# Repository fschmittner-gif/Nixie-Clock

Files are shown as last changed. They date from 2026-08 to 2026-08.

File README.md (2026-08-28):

# Nixie Clock

The goal of this project is to build your own Nixie Clock and get a result like this: 

NixieClockPNG

## Resources
### Controlling the Tubes

The project is based on the idea of controlling the Nixie tubes with old russian driver parts utilizing an arduino nano based on this [article](https://www.instructables.com/Controlling-Nixie-Tube-With-Arduino-Using-K155ID1-/) 

Tubes

### Real Time Clock (RTC)

In order to keep the time during a power outage or when moving the clock a RTC added to the project. For this purpose the DS3231 was used due to its low cost, easy I2C comunnication and available Arduino libraries.

RTC

## Designing the PCB

For the PCB Design a Schematic and Layout were designed in Fusion 360 and available for download and use. Before ordering your own PCBs, the DC Jack placement should be adapted as in the current design it sits inverted on the TOP Side. For my build, I fixed it by manipulating the installed DC Jack before soldering it onto the PCB.  

Rendering of PCB V1:

Schematic V1 3D BOTTOM
Schematic V1 3D TOP

## BOM

| Reference Designators | Quantity | Description | Package | Value |
|---|---|---|---|---|
| ARDUINO_NANO | 1 | Arduino Nano V3.0 | ARDUINO_NANO |  |
| C1, C2, C3, C4, C5 | 5 | CAPACITOR, European symbol | C0603 | 100n |
| C6, C7 | 2 | CAPACITOR, European symbol | C0603 | 10u |
| D1 | 1 | DCDC Converter | NIXIE_DCDC | DCDC_NIXIE |
| DC_JACK | 1 | 2.1mm x 5.5mm THM DC jack with internal switch. Digikey part #PJ-102A, 4UCON part #05537 | PJ-102A | 2.1MMJACKTHM |
| DCDC_IN, DCDC_OUT | 2 | PIN HEADER | 1X02 |  |
| L1 | 1 | Linear Regulator 5V | TO220 | L7805_5V |
| NX1, NX2, NX3, NX4 | 4 | IN-14: medium numeric frontview nixie tube | IN-14 | IN-14 |
| R1, R2, R3, R4 | 4 | RESISTOR, European symbol | R1206 | 10k |
| RTC | 1 | RTC Module with Battery and EEPROM based on DS3231 and AT24C32 chips | RTC-DS3231-AT24C32 | RTC-DS3231-AT24C32 |
| U1, U2, U3, U4 | 4 | Nixie Drivers | DIL16 | K155ID1 |

## Software

The Software is split into 2 parts: "SetTime" and "Control".

First the "SetTime" code has to be flashed to the Arduino in order to set the RTC to the current time. Afterwards the "Coltrol" code shall be flashed to actually display the time on the Nixie Tubes. I recommend using the Arduino IDE for programming.

## Case

A ready to print 3D case for the designed PCB is available to download. 

Gehäuse V2

## Lizenzierung

Dieses Projekt ist dual lizenziert:
- Die **Software und Firmware** steht unter der [Apache 2.0 Lizenz](LICENSE-SOFTWARE).
- Die **Hardware-Designs** (Schaltpläne, CAD-Daten, PCB-Layouts) stehen unter der [CERN-OHL-P v2 Lizenz](LICENSE-HARDWARE).

Beide Lizenzen schließen jegliche Haftung oder Gewährleistung aus. Die Nutzung erfolgt auf eigene Gefahr.

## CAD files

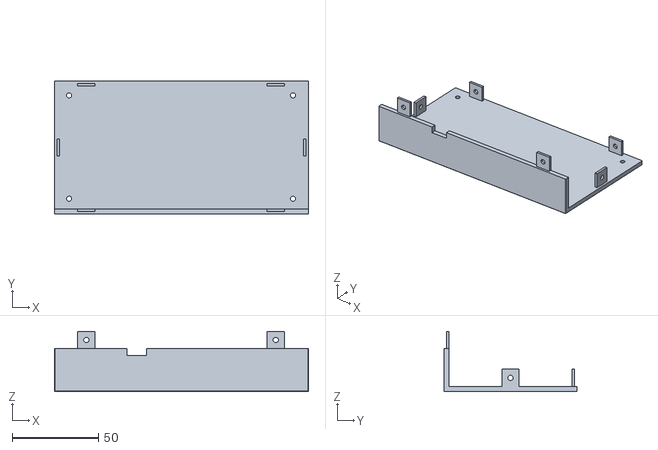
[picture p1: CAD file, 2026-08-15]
Housing/Bottom_V2.stl
147.5 x 77.5 x 35.0

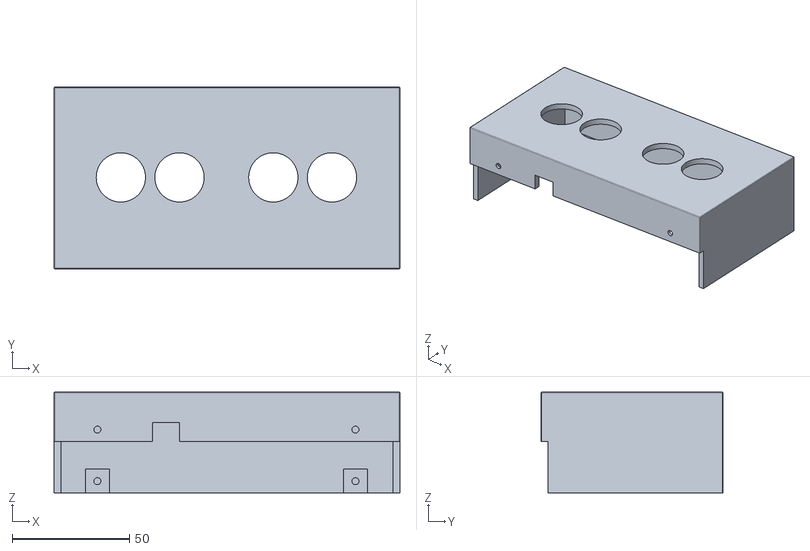
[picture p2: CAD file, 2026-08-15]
Housing/Top_V2.stl
147.5 x 77.5 x 43.0

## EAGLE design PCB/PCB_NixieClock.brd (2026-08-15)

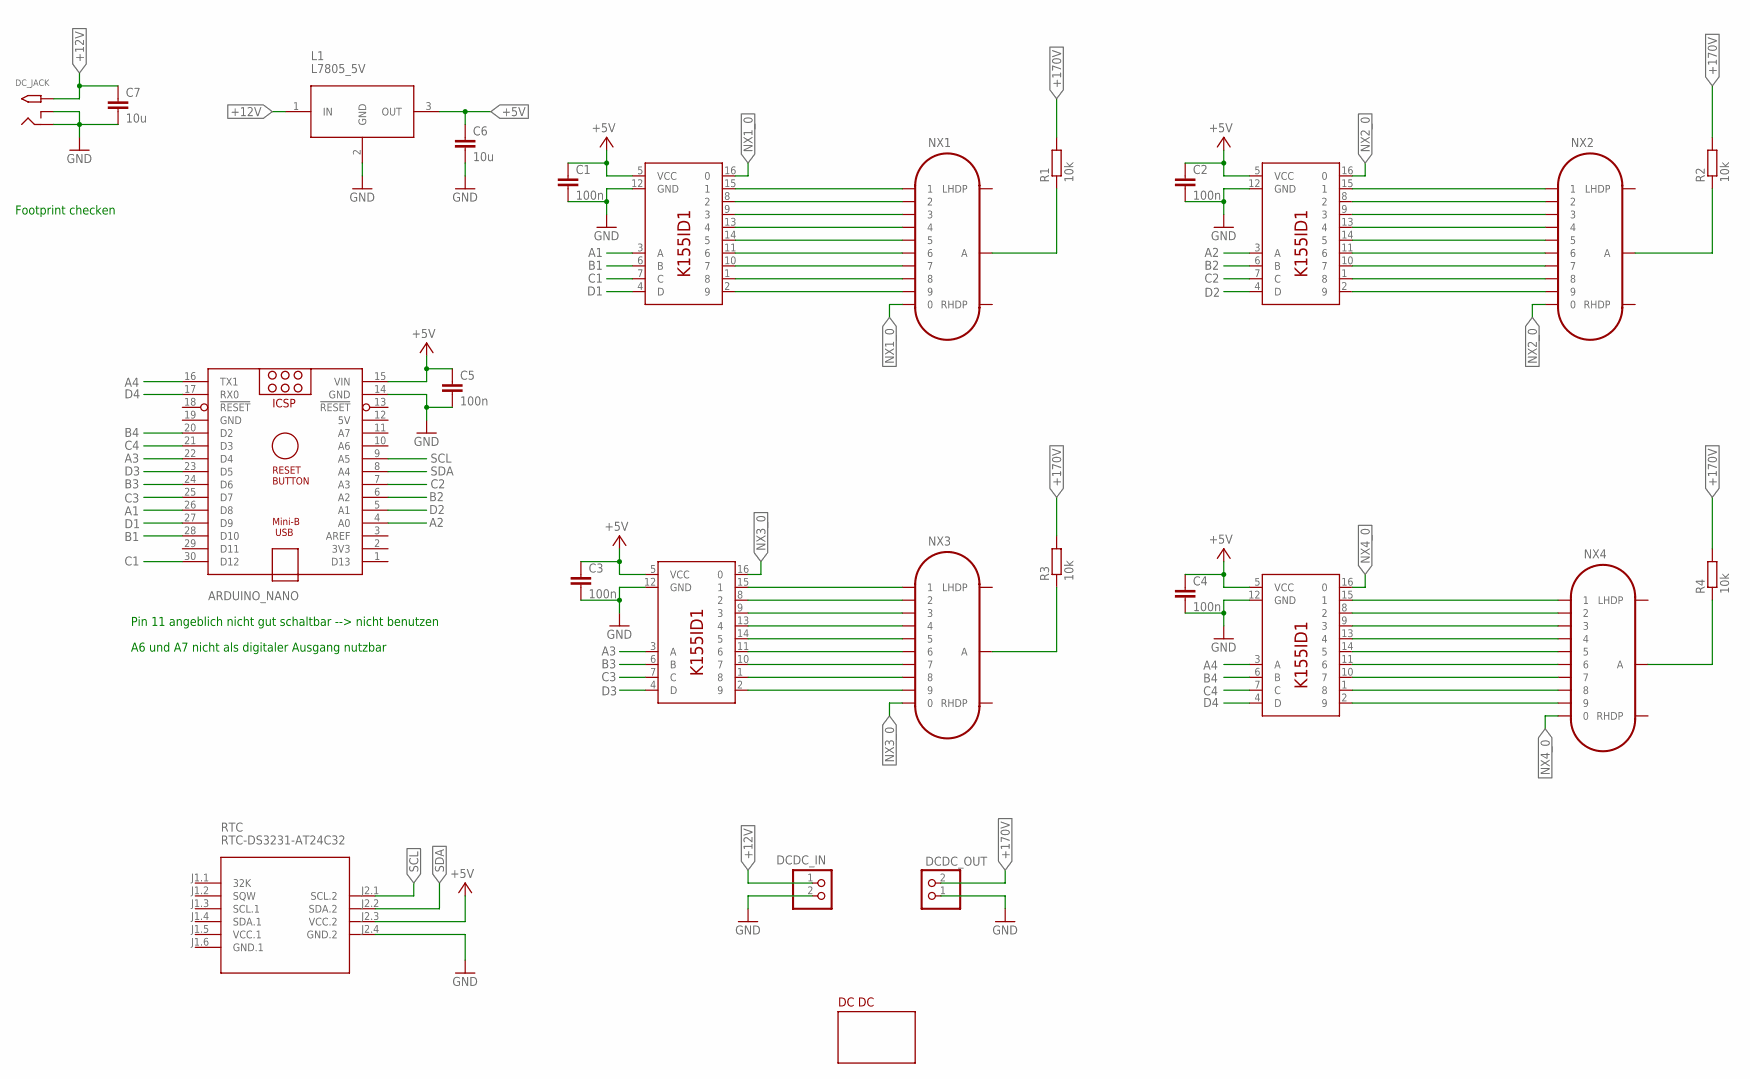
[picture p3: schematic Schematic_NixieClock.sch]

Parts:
ARDUINO_NANO: ARDUINO_NANO
C1, C2, C3, C4, C5: 100n; C0603
C6, C7: 10u; C0603
D1: DCDC_NIXIE; NIXIE_DCDC
DCDC_IN: PINHD-1X2; 1X02
DCDC_OUT: PINHD-1X2; 1X02
DC_JACK: 2.1MMJACKTHM; PJ-102A
L1: L7805_5V; TO220
NX1, NX2, NX3, NX4: IN-14
R1, R2, R3, R4: 10k; R1206
RTC: RTC-DS3231-AT24C32
U1, U2, U3, U4: K155ID1; DIL16

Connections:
5V: ARDUINO_NANO.12 (5V)
+5V: ARDUINO_NANO.15 (VIN), C1.1, C2.1, C3.1, C4.1, C5.1, C6.1, L1.3 (OUT), RTC.J2.3 (VCC.2), U1.5 (VCC), U2.5 (VCC), U3.5 (VCC), U4.5 (VCC)
+12V: C7.1, DCDC_IN.1, DC_JACK.TIP, L1.1 (IN)
+170V: DCDC_OUT.2, R1.2, R2.2, R3.2, R4.2
A1: ARDUINO_NANO.26 (D8), U1.3 (A)
A2: ARDUINO_NANO.4 (A0), U3.3 (A)
A3: ARDUINO_NANO.22 (D4), U2.3 (A)
A4: ARDUINO_NANO.16 (TX1), U4.3 (A)
B1: ARDUINO_NANO.28 (D10), U1.6 (B)
B2: ARDUINO_NANO.6 (A2), U3.6 (B)
B3: ARDUINO_NANO.24 (D6), U2.6 (B)
B4: ARDUINO_NANO.20 (D2), U4.6 (B)
C1: ARDUINO_NANO.30 (D12), U1.7 (C)
C2: ARDUINO_NANO.7 (A3), U3.7 (C)
C3: ARDUINO_NANO.25 (D7), U2.7 (C)
C4: ARDUINO_NANO.21 (D3), U4.7 (C)
D1: ARDUINO_NANO.27 (D9), U1.4 (D)
D2: ARDUINO_NANO.5 (A1), U3.4 (D)
D3: ARDUINO_NANO.23 (D5), U2.4 (D)
D4: ARDUINO_NANO.17 (RX0), U4.4 (D)
GND: ARDUINO_NANO.14 (GND), ARDUINO_NANO.19 (GND), C1.2, C2.2, C3.2, C4.2, C5.2, C6.2, C7.2, DCDC_IN.2, DCDC_OUT.1, DC_JACK.RING, DC_JACK.RING_SW, L1.2 (GND), RTC.J2.4 (GND.2), U1.12 (GND), U2.12 (GND), U3.12 (GND), U4.12 (GND)
GND.1: RTC.J1.6 (GND.1)
unnamed: NX1.1, U1.15 (1)
unnamed: NX1.2, U1.8 (2)
unnamed: NX1.3, U1.9 (3)
unnamed: NX1.4, U1.13 (4)
unnamed: NX1.5, U1.14 (5)
unnamed: NX1.6, U1.11 (6)
unnamed: NX1.7, U1.10 (7)
unnamed: NX1.8, U1.1 (8)
unnamed: NX1.9, U1.2 (9)
unnamed: NX3.1, U2.15 (1)
unnamed: NX3.2, U2.8 (2)
unnamed: NX3.3, U2.9 (3)
unnamed: NX3.4, U2.13 (4)
unnamed: NX3.5, U2.14 (5)
unnamed: NX3.6, U2.11 (6)
unnamed: NX3.7, U2.10 (7)
unnamed: NX3.8, U2.1 (8)
unnamed: NX3.9, U2.2 (9)
unnamed: NX2.1, U3.15 (1)
unnamed: NX2.2, U3.8 (2)
unnamed: NX2.3, U3.9 (3)
unnamed: NX2.4, U3.13 (4)
unnamed: NX2.5, U3.14 (5)
unnamed: NX2.6, U3.11 (6)
unnamed: NX2.7, U3.10 (7)
unnamed: NX2.8, U3.1 (8)
unnamed: NX2.9, U3.2 (9)
unnamed: NX4.1, U4.15 (1)
unnamed: NX4.2, U4.8 (2)
unnamed: NX4.3, U4.9 (3)
unnamed: NX4.4, U4.13 (4)
unnamed: NX4.5, U4.14 (5)
unnamed: NX4.6, U4.11 (6)
unnamed: NX4.7, U4.10 (7)
unnamed: NX4.8, U4.1 (8)
unnamed: NX4.9, U4.2 (9)
unnamed: NX3.A, R3.1
unnamed: NX1.A, R1.1
unnamed: NX2.A, R2.1
unnamed: NX4.A, R4.1
NX1_0: NX1.0, U1.16 (0)
NX2_0: NX2.0, U3.16 (0)
NX3_0: NX3.0, U2.16 (0)
NX4_0: NX4.0, U4.16 (0)
SCL: ARDUINO_NANO.9 (A5), RTC.J2.1 (SCL.2)
SDA: ARDUINO_NANO.8 (A4), RTC.J2.2 (SDA.2)
VCC.1: RTC.J1.5 (VCC.1)

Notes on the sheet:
Pin 11 angeblich nicht gut schaltbar --> nicht benutzen
A6 und A7 nicht als digitaler Ausgang nutzbar
Footprint checken

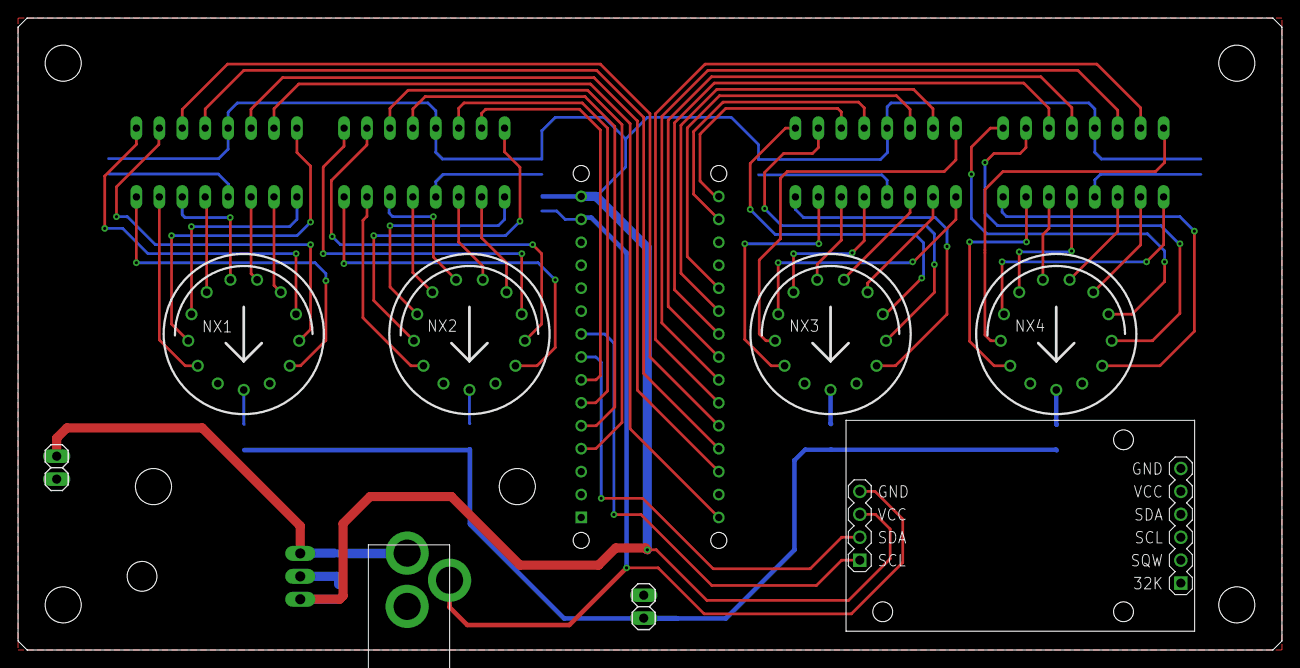
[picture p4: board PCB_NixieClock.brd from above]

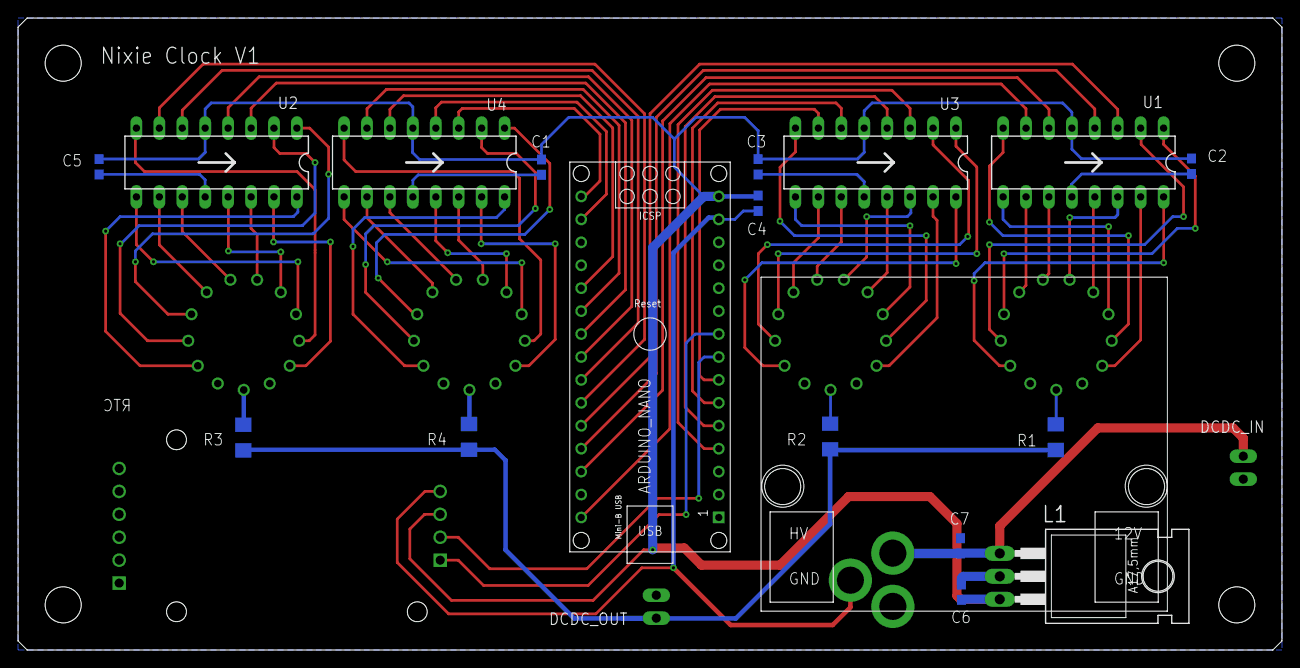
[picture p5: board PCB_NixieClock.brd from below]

Board: 2 copper layers, 140.0 x 70.0 mm, 26 parts (18 on the bottom side), 66 nets.

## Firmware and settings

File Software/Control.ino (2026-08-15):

#include <Wire.h>
#include <TimeLib.h>
#include <DS1307RTC.h>

#define A1 8
#define B1 10
#define C1 12
#define D1 9
#define A2 14
#define B2 15
#define C2 16
#define D2 17
#define A3 4
#define B3 6
#define C3 7
#define D3 5
#define A4 0
#define B4 2
#define C4 3
#define D4 1

char A[4] = {A1, A2, A3, A4};
char B[4] = {B1, B2, B3, B4};
char C[4] = {C1, C2, C3, C4};
char D[4] = {D1, D2, D3, D4};



const char *monthName[12] = {
  "Jan", "Feb", "Mar", "Apr", "May", "Jun",
  "Jul", "Aug", "Sep", "Oct", "Nov", "Dec"
};

tmElements_t tm;
int hour1, hour2, minute1, minute2;

void setup() {

  pinMode(A1, OUTPUT);
  pinMode(B1, OUTPUT);
  pinMode(C1, OUTPUT);
  pinMode(D1, OUTPUT);
  pinMode(A2, OUTPUT);
  pinMode(B2, OUTPUT);
  pinMode(C2, OUTPUT);
  pinMode(D2, OUTPUT);
  pinMode(A3, OUTPUT);
  pinMode(B3, OUTPUT);
  pinMode(C3, OUTPUT);
  pinMode(D3, OUTPUT);
  pinMode(A4, OUTPUT);
  pinMode(B4, OUTPUT);
  pinMode(C4, OUTPUT);
  pinMode(D4, OUTPUT);
 // pinMode(pot, INPUT);
  for (char i = 0; i < 4; i++) {
    digitalWrite(A[i], LOW);
    digitalWrite(B[i], LOW);
    digitalWrite(C[i], LOW);
    digitalWrite(D[i], LOW);
  }
  
  bool parse=false;
  bool config=false;

  // get the date and time the compiler was run
//  if (getDate(__DATE__) && getTime(__TIME__)) {
//    parse = true;
//    // and configure the RTC with this info
//    if (RTC.write(tm)) {
//      config = true;
//    }
//  }

  //Serial.begin(9600);
  while (!Serial) ; // wait for Arduino Serial Monitor
  delay(200);
  if (parse && config) {
    Serial.print("DS1307 configured Time=");
    Serial.print(__TIME__);
    Serial.print(", Date=");
    Serial.println(__DATE__);
  } else if (parse) {
    Serial.println("DS1307 Communication Error :-{");
    Serial.println("Please check your circuitry");
  } else {
    Serial.print("Could not parse info from the compiler, Time=\"");
    Serial.print(__TIME__);
    Serial.print("\", Date=\"");
    Serial.print(__DATE__);
    Serial.println("\"");
  }
}

void loop() {
  tmElements_t tm;

  if (RTC.read(tm)) {
    Serial.print("Ok, Time = ");
    print2digits(tm.Hour);
    Serial.write(':');
    print2digits(tm.Minute);
    Serial.write(':');
    print2digits(tm.Second);
    Serial.print(", Date (D/M/Y) = ");
    Serial.print(tm.Day);
    Serial.write('/');
    Serial.print(tm.Month);
    Serial.write('/');
    Serial.print(tmYearToCalendar(tm.Year));
    Serial.println();
  } else {
    if (RTC.chipPresent()) {
      Serial.println("The DS1307 is stopped.  Please run the SetTime");
      Serial.println("example to initialize the time and begin running.");
      Serial.println();
    } else {
      Serial.println("DS1307 read error!  Please check the circuitry.");
      Serial.println();
    }
    delay(9000);
  }

  hour1 = tm.Hour /10;
  hour2 = tm.Hour - 10*hour1;

  minute1 = tm.Minute /10;
  minute2 = tm.Minute -10*minute1; 

//  Serial.print("hour1= ");
//  Serial.print(hour1);
//  Serial.print("hour2= ");
//  Serial.print(hour2);
//
//  Serial.print("minute1= ");
//  Serial.print(minute1);
//  Serial.print("minute2= ");
//  Serial.print(minute2);


  writenumber(3,hour2);
  writenumber(4,hour1);
  writenumber(2,minute1);
  writenumber(1,minute2);
  
  delay(1000);

}

void print2digits(int number) {
  if (number >= 0 && number < 10) {
    Serial.write('0');
  }
  Serial.print(number);
}

bool getTime(const char *str)
{
  int Hour, Min, Sec;

  if (sscanf(str, "%d:%d:%d", &Hour, &Min, &Sec) != 3) return false;
  tm.Hour = Hour;
  tm.Minute = Min;
  tm.Second = Sec;
  return true;
}

bool getDate(const char *str)
{
  char Month[12];
  int Day, Year;
  uint8_t monthIndex;

  if (sscanf(str, "%s %d %d", Month, &Day, &Year) != 3) return false;
  for (monthIndex = 0; monthIndex < 12; monthIndex++) {
    if (strcmp(Month, monthName[monthIndex]) == 0) break;
  }
  if (monthIndex >= 12) return false;
  tm.Day = Day;
  tm.Month = monthIndex + 1;
  tm.Year = CalendarYrToTm(Year);
  return true;
}

void writenumber(int a, int b) {        // a: 4 == hour1 3 == hour2 2 == minute1 1 == minute2 

  int x,y,z,i;
  switch (a) {
    case 1:
      x = 8;
      y = 9;
      z = 10;
      i = 12;
      break;
    case 2:
      x = 14;
      y = 15;
      z = 16;
      i = 17;
      break;
    case 4: 
      x = 4;
      y = 5;
      z = 6;
      i = 7;
      break;
    case 3: 
      x = 0;
      y = 1;
      z = 2;
      i = 3;
      break; 
  }
    
  
  switch (b) {
    case 0:
      if(a == 3){
      digitalWrite(x, LOW);
      digitalWrite(y, HIGH);
      digitalWrite(z, LOW);
      digitalWrite(i, LOW); //0
      }else{
      digitalWrite(x, HIGH);
      digitalWrite(y, LOW);
      digitalWrite(z, LOW);
      digitalWrite(i, LOW); //0  
      }    
      break;
    case 9:
      if(a == 3){
      digitalWrite(x, LOW);
      digitalWrite(y, LOW);
      digitalWrite(z, HIGH);
      digitalWrite(i, LOW); //9
      }else{
      digitalWrite(x, LOW);
      digitalWrite(y, LOW);
      digitalWrite(z, HIGH);
      digitalWrite(i, LOW); //9  
      }    
      break;
    case 8:
      if(a == 3){
      digitalWrite(x, LOW);
      digitalWrite(y, HIGH);
      digitalWrite(z, HIGH);
      digitalWrite(i, LOW); //8
      }else{
      digitalWrite(x, HIGH);
      digitalWrite(y, LOW);
      digitalWrite(z, HIGH);
      digitalWrite(i, LOW); //8  
      }
      break;
    case 7:
      if(a == 3){
      digitalWrite(x, LOW);
      digitalWrite(y, LOW);
      digitalWrite(z, LOW);
      digitalWrite(i, HIGH); //7
      }else{
      digitalWrite(x, LOW);
      digitalWrite(y, LOW);
      digitalWrite(z, LOW);
      digitalWrite(i, HIGH); //7  
      }
      break;
    case 6:
      if(a == 3){
      digitalWrite(x, LOW);
      digitalWrite(y, HIGH);
      digitalWrite(z, LOW);
      digitalWrite(i, HIGH); //6
      }else{
      digitalWrite(x, HIGH);
      digitalWrite(y, LOW);
      digitalWrite(z, LOW);
      digitalWrite(i, HIGH); //6  
      }
      break;
    case 5:
      if(a == 3){
      digitalWrite(x, LOW);
      digitalWrite(y, LOW);
      digitalWrite(z, HIGH);
      digitalWrite(i, HIGH); //5
      }else{
      digitalWrite(x, LOW);
      digitalWrite(y, LOW);
      digitalWrite(z, HIGH);
      digitalWrite(i, HIGH); //5  
      }
      break;
    case 4:
      if(a == 3){
      digitalWrite(x, LOW);
      digitalWrite(y, HIGH);
      digitalWrite(z, HIGH);
      digitalWrite(i, HIGH); //4
      }else{
      digitalWrite(x, HIGH);
      digitalWrite(y, LOW);
      digitalWrite(z, HIGH);
      digitalWrite(i, HIGH); //4  
      }
      break;
    case 3:
      if(a == 3){
      digitalWrite(x, HIGH);
      digitalWrite(y, LOW);
      digitalWrite(z, LOW);
      digitalWrite(i, LOW); //3
      }else{
      digitalWrite(x, LOW);
      digitalWrite(y, HIGH);
      digitalWrite(z, LOW);
      digitalWrite(i, LOW); //3  
      }
      break;
    case 2:
      if(a == 3){
      digitalWrite(x, HIGH);
      digitalWrite(y, HIGH);
      digitalWrite(z, LOW);
      digitalWrite(i, LOW); //2
      }else{
      digitalWrite(x, HIGH);
      digitalWrite(y, HIGH);
      digitalWrite(z, LOW);
      digitalWrite(i, LOW); //2  
      }
      break;
    case 1:
      if(a == 3){
      digitalWrite(x, LOW);
      digitalWrite(y, LOW);
      digitalWrite(z, LOW);
      digitalWrite(i, LOW); //1
      }else{
      digitalWrite(x, LOW);
      digitalWrite(y, LOW);
      digitalWrite(z, LOW);
      digitalWrite(i, LOW); //1  
      }
      break;
  }
}

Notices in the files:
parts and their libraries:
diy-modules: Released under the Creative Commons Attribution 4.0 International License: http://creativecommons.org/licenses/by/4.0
